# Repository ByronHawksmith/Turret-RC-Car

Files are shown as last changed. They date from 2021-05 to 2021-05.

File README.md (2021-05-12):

# Turret-RC-Car

Advanced IT Prototyping Concepts, Turret RC Car, SP2 2021 (https://vimeo.com/548205048 "Advanced IT Prototyping Concepts, Turret RC Car, SP2 2021")

## Attribution and Acknowledgements

- Pan Tilt Mechanism designed by Thingiverse user: eltitomanolo. Available at: https://www.thingiverse.com/thing:2467743
- Automated Gattling Turret designed by Thingiverse user: Canino. Available at: https://www.thingiverse.com/thing:3420083

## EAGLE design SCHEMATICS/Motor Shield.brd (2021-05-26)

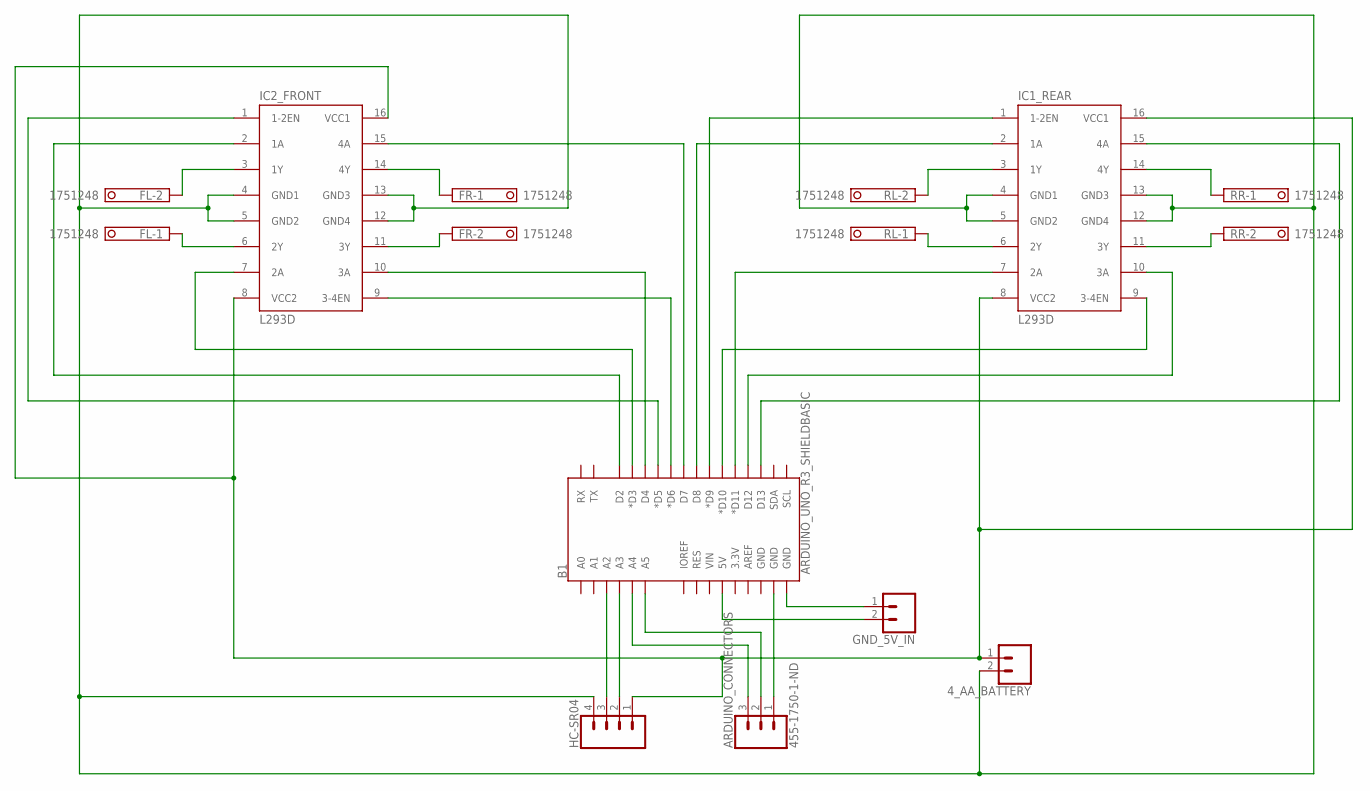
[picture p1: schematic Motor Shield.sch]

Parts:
4_AA_BATTERY: CONN_02; 1X02
ARDUINO_CONNECTORS: 455-1750-1-ND; 1X03
B1: ARDUINO_UNO_R3_SHIELDBASIC; UNO_R3_SHIELD
FL: 1751248
FR: 1751248
GND_5V_IN: CONN_02; 1X02
HC-SR04: CONN_04PTH; 1X04
IC1_REAR, IC2_FRONT: L293D; DIL16
RL: 1751248
RR: 1751248

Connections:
D2: B1.D2, IC2_FRONT.2 (1A)
D3: B1.D3 (*D3), IC2_FRONT.7 (2A)
D5: B1.D5 (*D5), IC2_FRONT.1 (1-2EN)
GND: 4_AA_BATTERY.2, HC-SR04.4, IC1_REAR.4 (GND1), IC1_REAR.5 (GND2), IC1_REAR.12 (GND4), IC1_REAR.13 (GND3), IC2_FRONT.4 (GND1), IC2_FRONT.5 (GND2), IC2_FRONT.12 (GND4), IC2_FRONT.13 (GND3)
unnamed: FL.2, IC2_FRONT.3 (1Y)
unnamed: FL.1, IC2_FRONT.6 (2Y)
unnamed: FR.1, IC2_FRONT.14 (4Y)
unnamed: FR.2, IC2_FRONT.11 (3Y)
unnamed: IC1_REAR.3 (1Y), RL.2
unnamed: IC1_REAR.14 (4Y), RR.1
unnamed: IC1_REAR.6 (2Y), RL.1
unnamed: IC1_REAR.11 (3Y), RR.2
unnamed: B1.GND@0 (GND), GND_5V_IN.1
unnamed: B1.D10 (*D10), IC1_REAR.9 (3-4EN)
unnamed: B1.5V, GND_5V_IN.2
unnamed: B1.A2, HC-SR04.3
unnamed: B1.A3, HC-SR04.2
unnamed: B1.D11 (*D11), IC1_REAR.7 (2A)
unnamed: ARDUINO_CONNECTORS.3, B1.A4
unnamed: B1.D9 (*D9), IC1_REAR.1 (1-2EN)
unnamed: B1.D12, IC1_REAR.10 (3A)
unnamed: B1.D13, IC1_REAR.15 (4A)
unnamed: B1.D8, IC1_REAR.2 (1A)
unnamed: B1.D7, IC2_FRONT.15 (4A)
unnamed: B1.D6 (*D6), IC2_FRONT.9 (3-4EN)
unnamed: ARDUINO_CONNECTORS.2, B1.A5
unnamed: B1.D4, IC2_FRONT.10 (3A)
unnamed: ARDUINO_CONNECTORS.1, B1.GND@1 (GND)
VCC: 4_AA_BATTERY.1, HC-SR04.1, IC1_REAR.8 (VCC2), IC1_REAR.16 (VCC1), IC2_FRONT.8 (VCC2), IC2_FRONT.16 (VCC1)

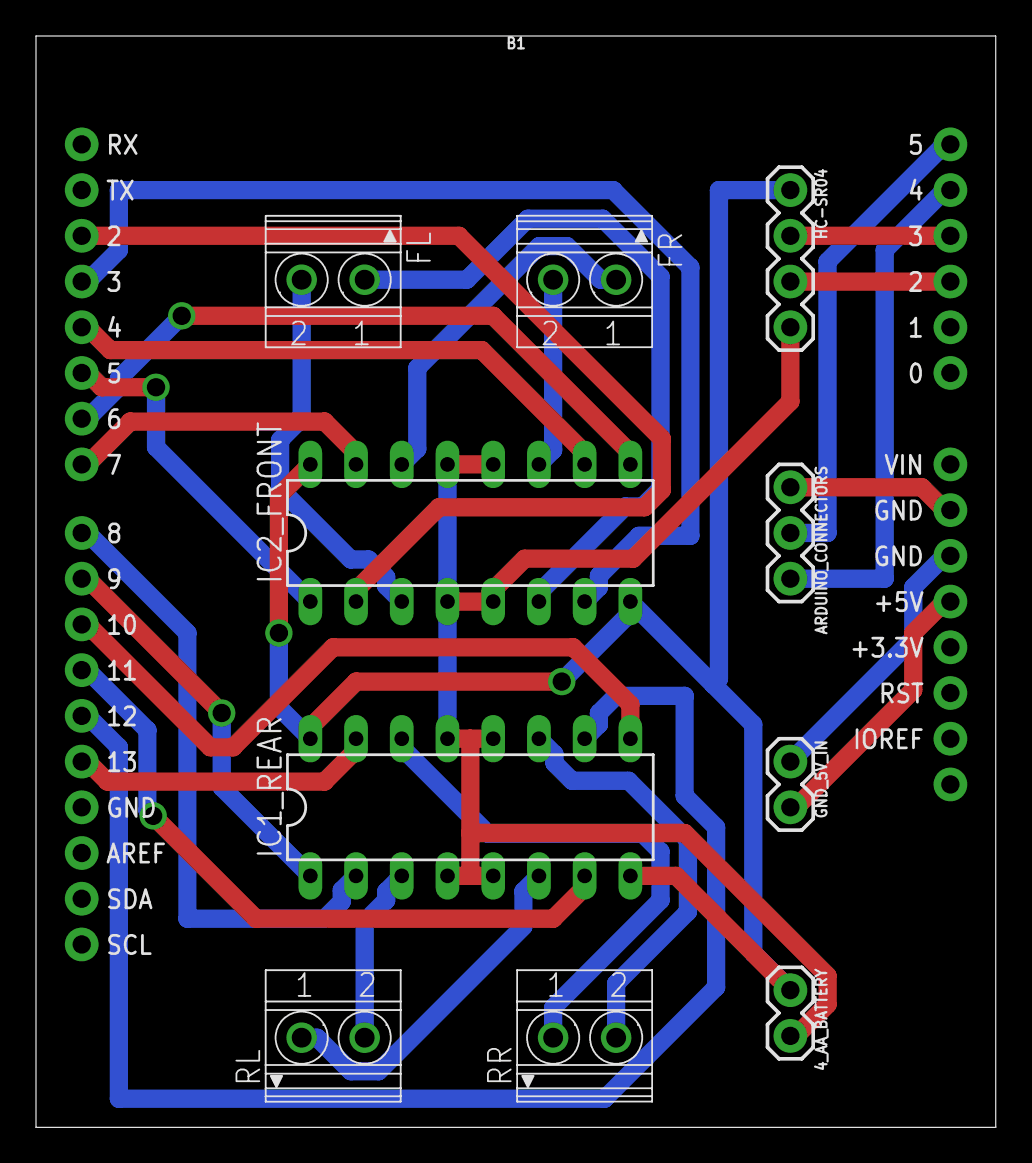
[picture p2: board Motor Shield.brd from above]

Board: 2 copper layers, 53.3 x 60.6 mm, 11 parts (0 on the bottom side), 29 nets.

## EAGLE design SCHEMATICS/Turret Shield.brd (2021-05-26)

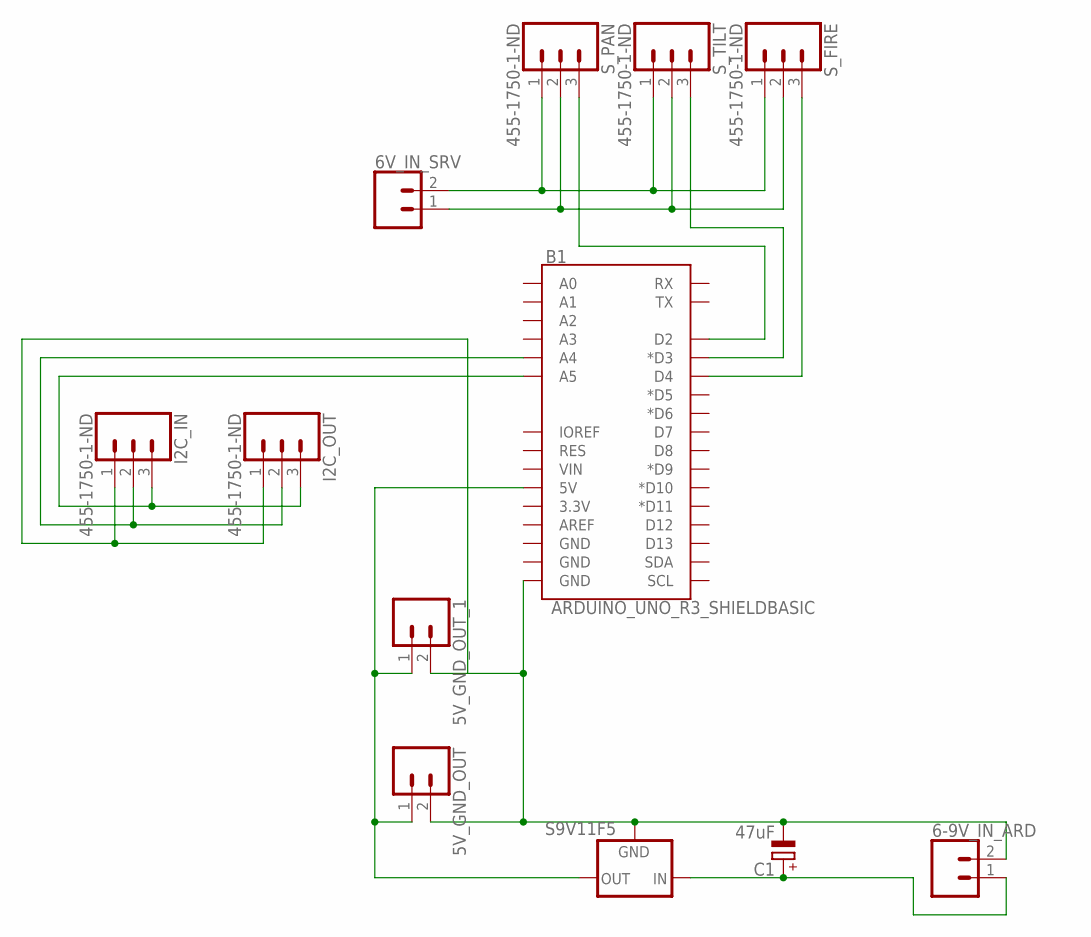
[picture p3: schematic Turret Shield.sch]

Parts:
5V_GND_OUT, 5V_GND_OUT_1, 6-9V_IN_ARD, 6V_IN_SRV: CONN_02; 1X02
B1: ARDUINO_UNO_R3_SHIELDBASIC; UNO_R3_SHIELD
C1: 47uF; E2,5-6
I2C_IN, I2C_OUT: 455-1750-1-ND; 1X03
S9V11F5: 78XXS
S_FIRE: 455-1750-1-ND; 1X03
S_PAN: 455-1750-1-ND; 1X03
S_TILT: 455-1750-1-ND; 1X03

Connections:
unnamed: 6V_IN_SRV.1, S_FIRE.2, S_PAN.2, S_TILT.2
unnamed: B1.D3 (*D3), S_TILT.3
unnamed: B1.D2, S_PAN.3
unnamed: 6V_IN_SRV.2, S_FIRE.1, S_PAN.1, S_TILT.1
unnamed: B1.D4, S_FIRE.3
unnamed: 5V_GND_OUT.2, 5V_GND_OUT_1.2, 6-9V_IN_ARD.2, B1.GND@0 (GND), C1.-, I2C_IN.1, I2C_OUT.1, S9V11F5.GND
unnamed: 5V_GND_OUT.1, 5V_GND_OUT_1.1, B1.5V, S9V11F5.OUT
unnamed: 6-9V_IN_ARD.1, C1.+, S9V11F5.IN
unnamed: B1.A5, I2C_IN.3, I2C_OUT.3
unnamed: B1.A4, I2C_IN.2, I2C_OUT.2

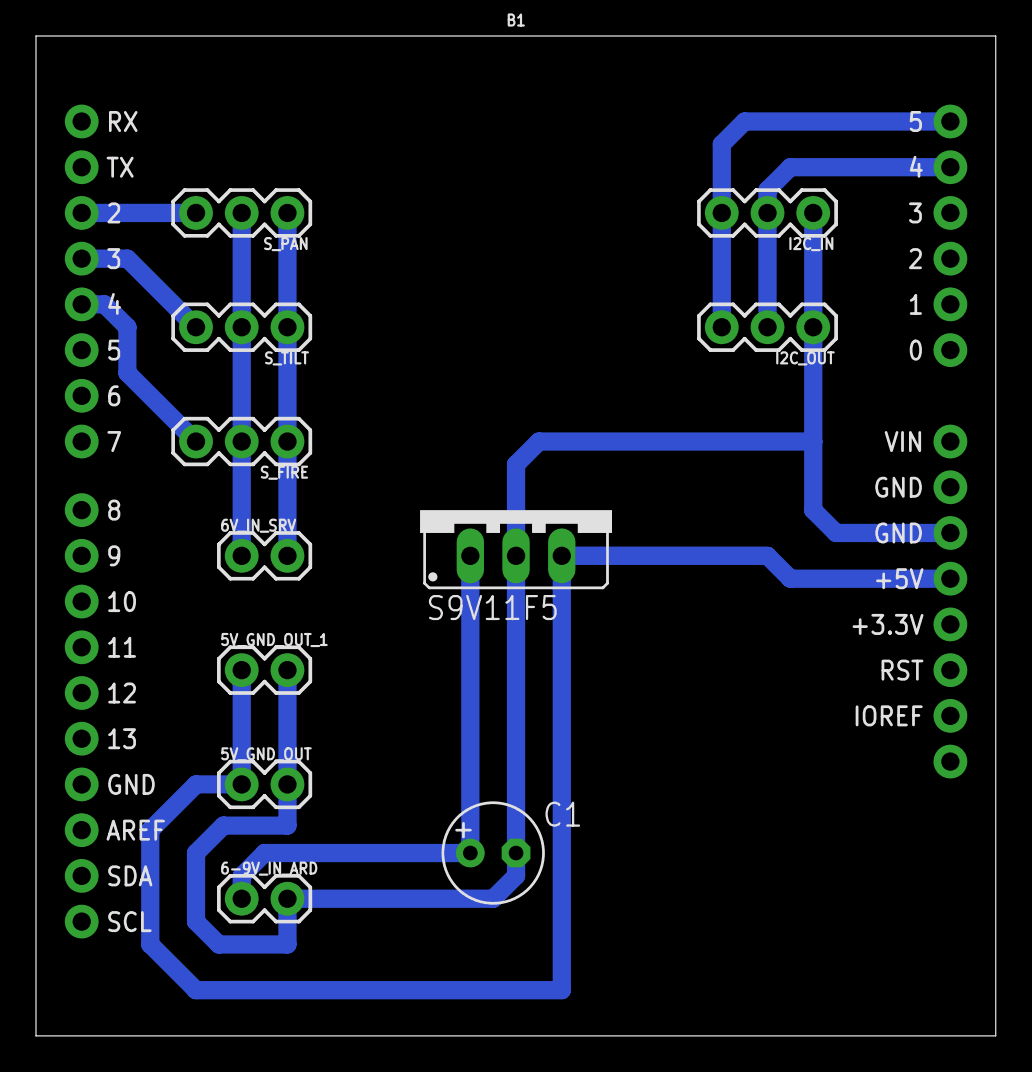
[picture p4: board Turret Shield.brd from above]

Board: 2 copper layers, 53.3 x 55.5 mm, 12 parts (0 on the bottom side), 10 nets.

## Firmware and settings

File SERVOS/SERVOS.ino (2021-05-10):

#include <Wire.h>
#include <Servo.h>

Servo panServo;   // create servo object to control a servo
Servo tiltServo;  // create servo object to control a servo
Servo fireServo;  // create servo object to control a servo

static volatile int right_hat_x;
static volatile int right_hat_y;
static volatile int r2_button;

void setup()
{
  panServo.attach(2);  
  tiltServo.attach(3);
  Wire.begin(9);                // join i2c bus with address #9
  Wire.onReceive(receiveEvent); // register event
  Serial.begin(115200);         // start serial for output
}

void loop()
{
  int my_right_hat_x, my_right_hat_y;
  
  noInterrupts();
    my_right_hat_x = right_hat_x;
    my_right_hat_y = right_hat_y;
  interrupts();
  
  panServo.write(my_right_hat_x);    
  tiltServo.write(my_right_hat_y);

  if(r2_button) {
    fireServo.attach(4);
  } else {
    fireServo.detach();
  }

  delay(100);
}

// function that executes whenever data is received from master
// this function is registered as an event, see setup()
void receiveEvent(int howMany)
{ 
  byte right_hat_x_lsb = Wire.read();
  byte right_hat_x_msb = Wire.read();
  byte right_hat_y_lsb = Wire.read();
  byte right_hat_y_msb = Wire.read();
  r2_button = Wire.read();

  right_hat_x = (right_hat_x_msb << 8) | right_hat_x_lsb;
  right_hat_y = (right_hat_y_msb << 8) | right_hat_y_lsb;
}

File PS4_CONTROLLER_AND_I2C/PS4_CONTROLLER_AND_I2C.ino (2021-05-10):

#include <PS4BT.h>
#include <Wire.h>

USB Usb;
BTD Btd(&Usb);
PS4BT PS4(&Btd, PAIR);

void setup() {
  Serial.begin(115200);

  if (Usb.Init() == -1) {
    Serial.print(F("\r\nOSC did not start"));
    while (1); // Halt
  }
  
  Serial.print(F("\r\nPS4 Bluetooth Library Started"));

  Wire.begin();
}

void loop() {
  Usb.Task();

  if (PS4.connected()) {
    int left_hat_x = PS4.getAnalogHat(LeftHatX);
    int left_hat_y = PS4.getAnalogHat(LeftHatY);

    byte left_hat_x_lsb = left_hat_x & 0xff;
    byte left_hat_x_msb = left_hat_x >> 8;
    byte left_hat_y_lsb = left_hat_y & 0xff;
    byte left_hat_y_msb = left_hat_y >> 8;

    byte left_hat_bytes[] = {
      left_hat_x_lsb,
      left_hat_x_msb,
      left_hat_y_lsb,
      left_hat_y_msb
    };

    int right_hat_x = map(PS4.getAnalogHat(RightHatX), 0, 255, 0, 180);
    int right_hat_y = map(PS4.getAnalogHat(RightHatY), 0, 255, 30, 150);

    byte right_hat_x_lsb = right_hat_x & 0xff;
    byte right_hat_x_msb = right_hat_x >> 8;
    byte right_hat_y_lsb = right_hat_y & 0xff;
    byte right_hat_y_msb = right_hat_y >> 8;
    byte r2_button = PS4.getAnalogButton(R2);

    byte right_hat_bytes[] = {
      right_hat_x_lsb,
      right_hat_x_msb,
      right_hat_y_lsb,
      right_hat_y_msb,
      r2_button
    };

    Wire.beginTransmission(8);                              // transmit to device #8
    Wire.write(left_hat_bytes, sizeof(left_hat_bytes));     // send bytes for left hat
    Wire.endTransmission();                                 // stop transmitting

    Wire.beginTransmission(9);                              // transmit to device #9
    Wire.write(right_hat_bytes, sizeof(right_hat_bytes));    // send bytes for right hat
    Wire.endTransmission();                                 // stop transmitting
  }
}

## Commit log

2021-05-10 Add in Wire I2C code.
2021-05-10 Get I2C Working, One Master, Multiple Slaves
2021-05-10 Get Pan and Tilt Servos working with I2C and PS4 Controller
2021-05-10 Get the worlds most terrible 'continuous rotation' servo (which spins the wrong way) working
    [PS4_CONTROLLER_AND_I2C.ino, SERVOS.ino]
2021-05-26 Add Schematics
    [Motor Shield.brd, Motor Shield.sch, Turret Shield.brd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]

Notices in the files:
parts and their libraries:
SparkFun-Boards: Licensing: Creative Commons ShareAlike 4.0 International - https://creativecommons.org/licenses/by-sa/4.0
